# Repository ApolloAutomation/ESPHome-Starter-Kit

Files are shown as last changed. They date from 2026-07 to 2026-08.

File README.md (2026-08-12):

# Official ESPHome Starter Kit

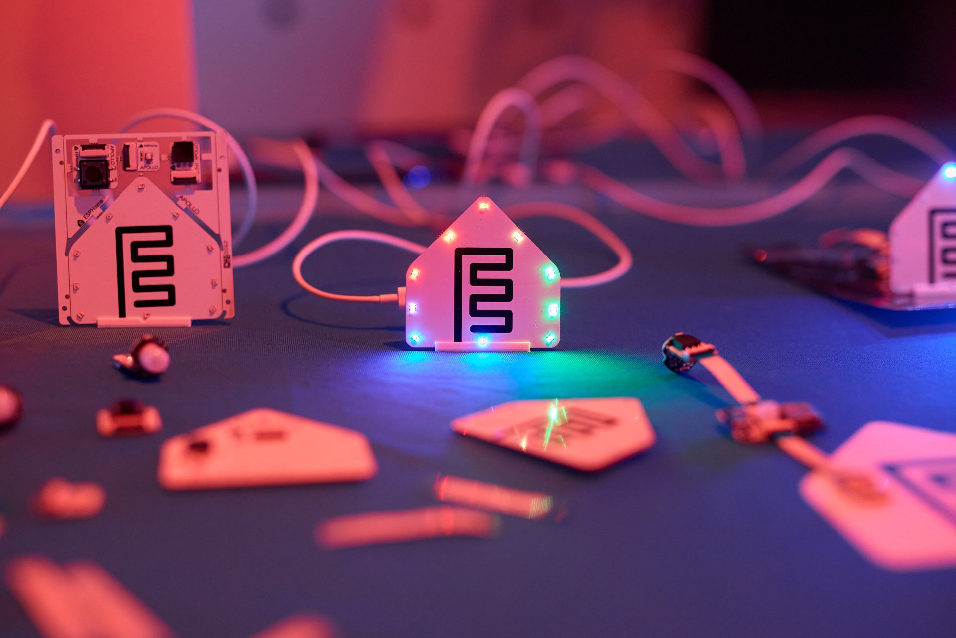
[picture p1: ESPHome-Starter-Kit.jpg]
ESPHome Starter Kit


The ESPHome Starter Kit is designed in collaboration with the **Open Home Foundation**. A portion of the profits from each sold goes directly to the OHF team to support their work on Home Assistant, ESPHome, Music Assistant, and other open-source smart home projects.

## Key Features

**ESP32-C6 Based:** Built on the ESP32-C6-mini module with Wi-Fi, Zigbee, and Thread radios for versatile smart home connectivity.

**Zigbee & Thread Support:** Dual antennas for Zigbee and Thread protocols. Supports Matter over Thread for future-proof smart home integration.

**USB-C Power:** USB-C port for easy power and programming.

**Expansion Ports:** Two 13-pin FPC cable ports allow you to connect and power virtually any sensor or accessory.

**Onboard Controls:** Boot and Reset buttons for easy flashing and debugging.

**Battery Powered:** Includes battery connector with MAX17048 fuel gauge for accurate voltage and percentage monitoring.

**Deep Sleep Support:** Configurable deep sleep duration for extended battery life. Wakes periodically to report sensor values and returns to sleep.

**Accessory Power Control:** GPIO-controlled power rail for connected accessories, automatically disabled during deep sleep to conserve battery.

## Specifications

| | |
|---|---|
| MCU | ESP32-C6-MINI-1 |
| Flash | 8 MB |
| Radios | Wi-Fi, Bluetooth, Zigbee, Thread |
| Framework | ESP-IDF (board `esp32-c6-devkitm-1`, variant `esp32c6`) |
| Power | USB-C, plus LiPo battery connector with MAX17048 fuel gauge |
| Expansion | Two 13-pin FPC ports with switchable accessory power rail |

## What's in the Kit

- **ESPHome C6 Board** - ESP32-C6 with dual FPC expansion ports
- **PIR Sensor** - Motion detection
- **Temperature/Humidity Sensor** - Environmental monitoring
- **Notification Puck** - LED and piezo buzzer PCB for visual and audio alerts
- **Button** - Physical input for triggering automations

## Pinout

| Function | GPIO |
|---|---|
| I2C SCL | GPIO0 |
| I2C SDA | GPIO1 |
| Motion module input (PIR) | GPIO3 |
| Accessory power (FPC rail control) | GPIO4 |
| Onboard RGB LED (WS2812) | GPIO5 |
| Button module input | GPIO6 |
| LED & Buzzer module LEDs (WS2812) | GPIO14 |
| LED & Buzzer module buzzer | GPIO18 |
| Boot button | GPIO9 |

### Breakout Module (optional add-on)

The [Breakout Module](https://wiki.apolloautomation.com/products/ESPHome-Starter-Kit/modules/apollo-breakout-module/) re-exposes the board's I2C bus and a shared GPIO across several connector types. It does not add new GPIOs.

| Connector | Signals |
|---|---|
| I2C ports (3.5mm jack, STEMMA QT 3.3V, STEMMA 5V, Grove, SEN6x) | SCL = GPIO0, SDA = GPIO1 |
| 1-Wire port | Data = GPIO6 |
| 3-pin STEMMA (5V) | GPIO6 (shared with 1-Wire), 5V, GND |
| 2x6 GPIO header | GPIO0 (SCL), GPIO1 (SDA), GPIO6, UART TX, UART RX, 3.3V, 5V, GND |

> **Note:** GPIO6 is shared between the 1-Wire port, the 3-pin STEMMA connector, and the GPIO header, so only one can be used at a time.

## ESPHome Integration

The starter kit is designed for use with ESPHome and Home Assistant. See the `Integrations/ESPHome/` folder for the YAML configuration.

### ESPHome Device Builder

The starter kit is an officially featured board in the [ESPHome Device Builder](https://github.com/esphome/device-builder). The easiest way to install firmware is straight from the Device Builder in your ESPHome dashboard — no default YAML to flash manually. You can see the board definition [here](https://github.com/esphome/device-builder/tree/main/esphome_device_builder/definitions/boards/apollo-esk-1).

## Hardware Files

3D models of the boards are in [`hardware/`](hardware/) for designing your own cases and mounts. Built something? See [CONTRIBUTING.md](CONTRIBUTING.md).

## Links

- **Product page:** [ESPHome Starter Kit on the Apollo shop](https://apolloautomation.com/products/esk-1-esphome-starter-kit)
- **Wiki (start here):** [ESPHome Starter Kit setup guide](https://wiki.apolloautomation.com/products/ESPHome-Starter-Kit/start-here/)
- **Forum:** [forum.apolloautomation.com](https://forum.apolloautomation.com/)
- **Discord** (support, feedback, discussion, future products): [dsc.gg/ApolloAutomation](http://dsc.gg/ApolloAutomation)
- **Open Home Foundation:** [openhomefoundation.org](https://www.openhomefoundation.org)

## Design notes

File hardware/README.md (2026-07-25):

# Hardware Files

3D models for the ESK-1 Starter Kit boards, provided so the community can design cases, mounts, and other accessories.

```
hardware/
├── cad/
│   └── pcb-placeholders/   # STEP models of each board — reference solids for case design
└── 3d-prints/
    └── Starter Kit Stand.stl
```

## `cad/pcb-placeholders/`

STEP models of the Starter Kit PCBs. These are **placeholders, not finished parts** — import them into your CAD tool as reference geometry to design enclosures and mounts that fit around the real boards.

| File | Board |
|---|---|
| `ESP32-C6 Mainboard.step` | ESK-1 main board |
| `PIR Module.step` | PIR motion sensor |
| `Temperature and Humidity Module.step` | Temp/humidity sensor |
| `LED and Buzzer Module.step` | Notification puck |
| `Button Module.step` | Button |
| `Breakout Module.step` | [Breakout Module](https://wiki.apolloautomation.com/products/ESPHome-Starter-Kit/modules/apollo-breakout-module/) (optional add-on, sold separately) |

## `3d-prints/`

Ready-to-print parts. Slice and print as-is.

| File | Part |
|---|---|
| `Starter Kit Stand.stl` | Display/desk stand for the kit |

## Contributing designs

Built a case or mount you'd like to share? See [CONTRIBUTING.md](../CONTRIBUTING.md).

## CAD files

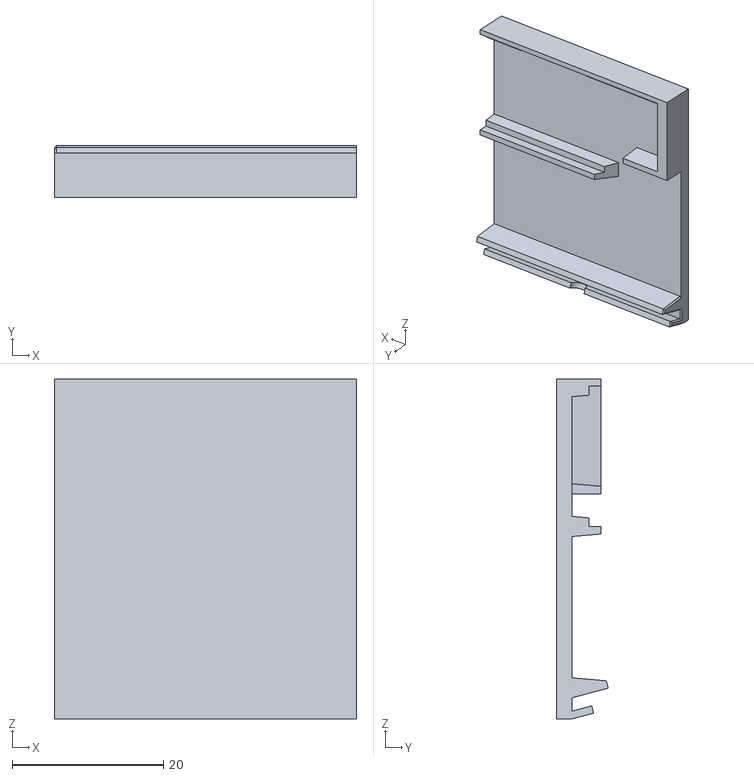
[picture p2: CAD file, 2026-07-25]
hardware/3d-prints/Starter Kit Stand.stl
40.0 x 6.83 x 45.0

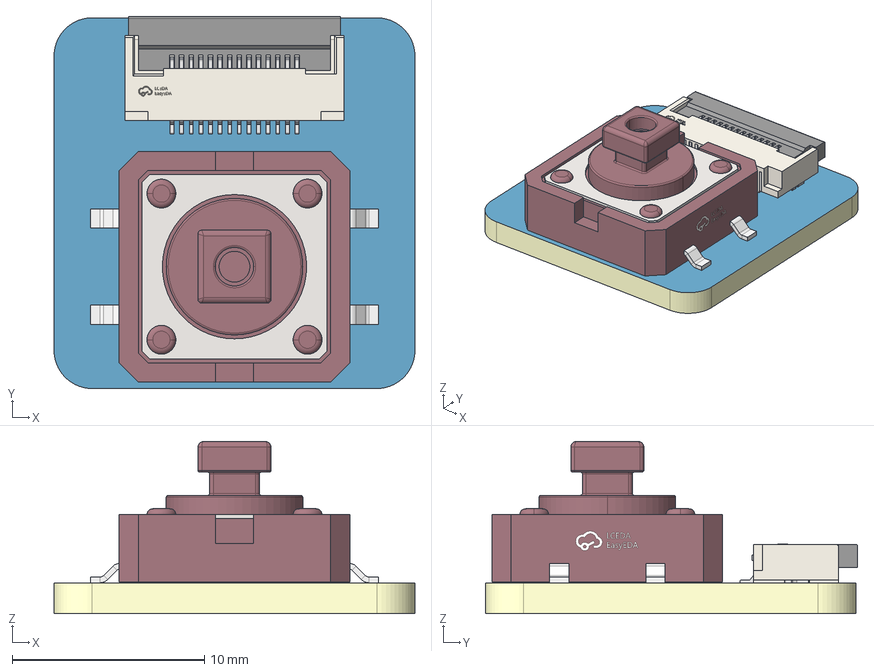
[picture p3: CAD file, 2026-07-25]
hardware/cad/pcb-placeholders/Button Module.step
18.8 x 19.3 x 8.95 mm
Board~eu64
TopCopper~eu64
BottomCopper~eu64
TopFpcStiffener~eu64
BottomFpcStiffener~eu64
KEY-SMD_4P-L12.0-W12.0-P5.00-LS15.0~KEY-SMD_ 4P-L12.0-W12.0-H7.3-LS15.0-P5.0~eu64
FPC-SMD_AFC01-S14FCA-00~FPC-SMD_AFC01-S14FCA-00~eu64

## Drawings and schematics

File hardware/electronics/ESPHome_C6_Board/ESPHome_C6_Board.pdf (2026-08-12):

# USB Connector Step Down 3.3V Handling

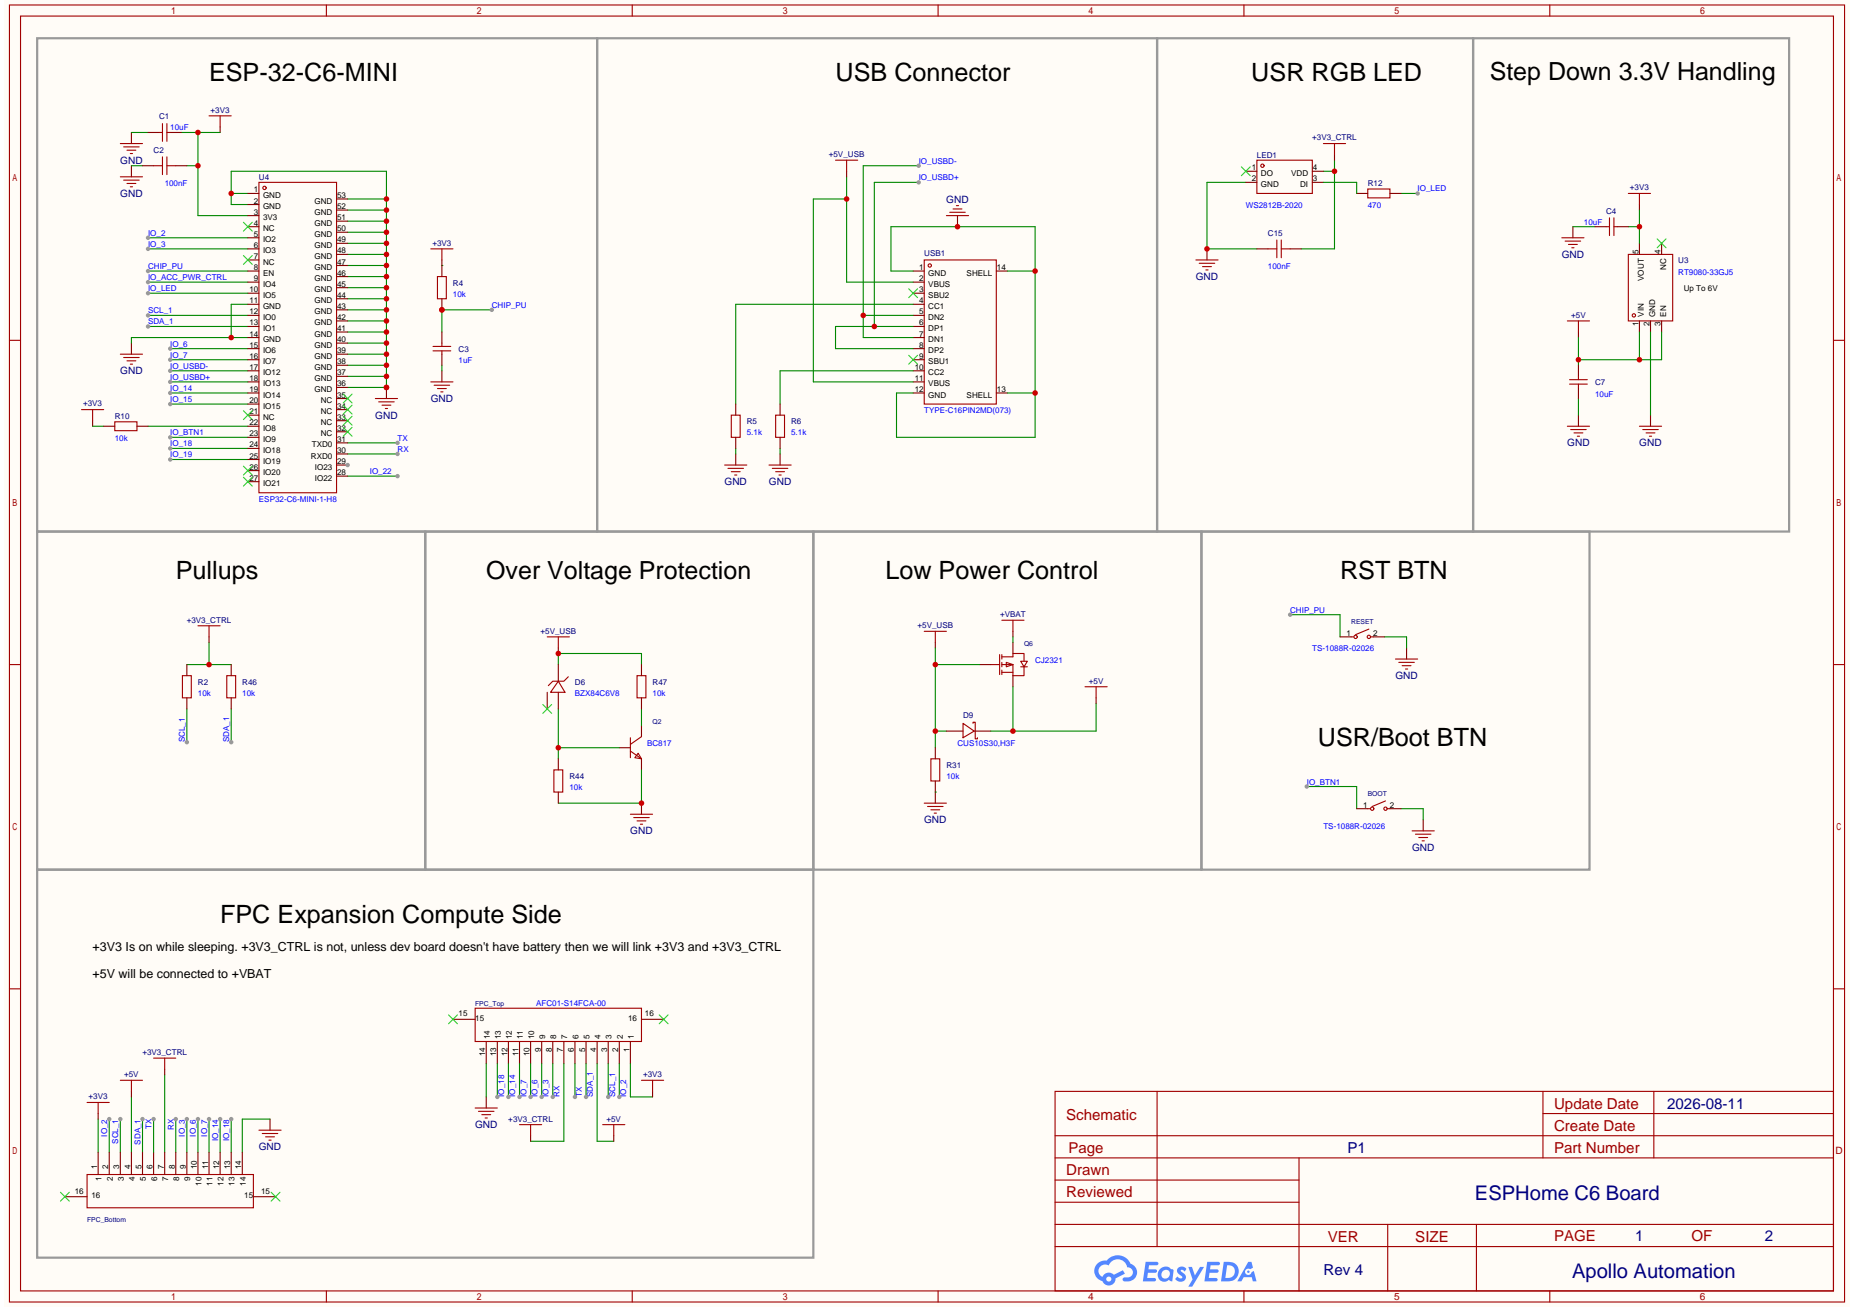
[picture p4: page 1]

FPC Expansion Compute Side

+3V3 Is on while sleeping. +3V3_CTRL is not, unless dev board doesn't have battery then we will link +3V3 and +3V3_CTRL

# Battery Measurement

# Battery Protection

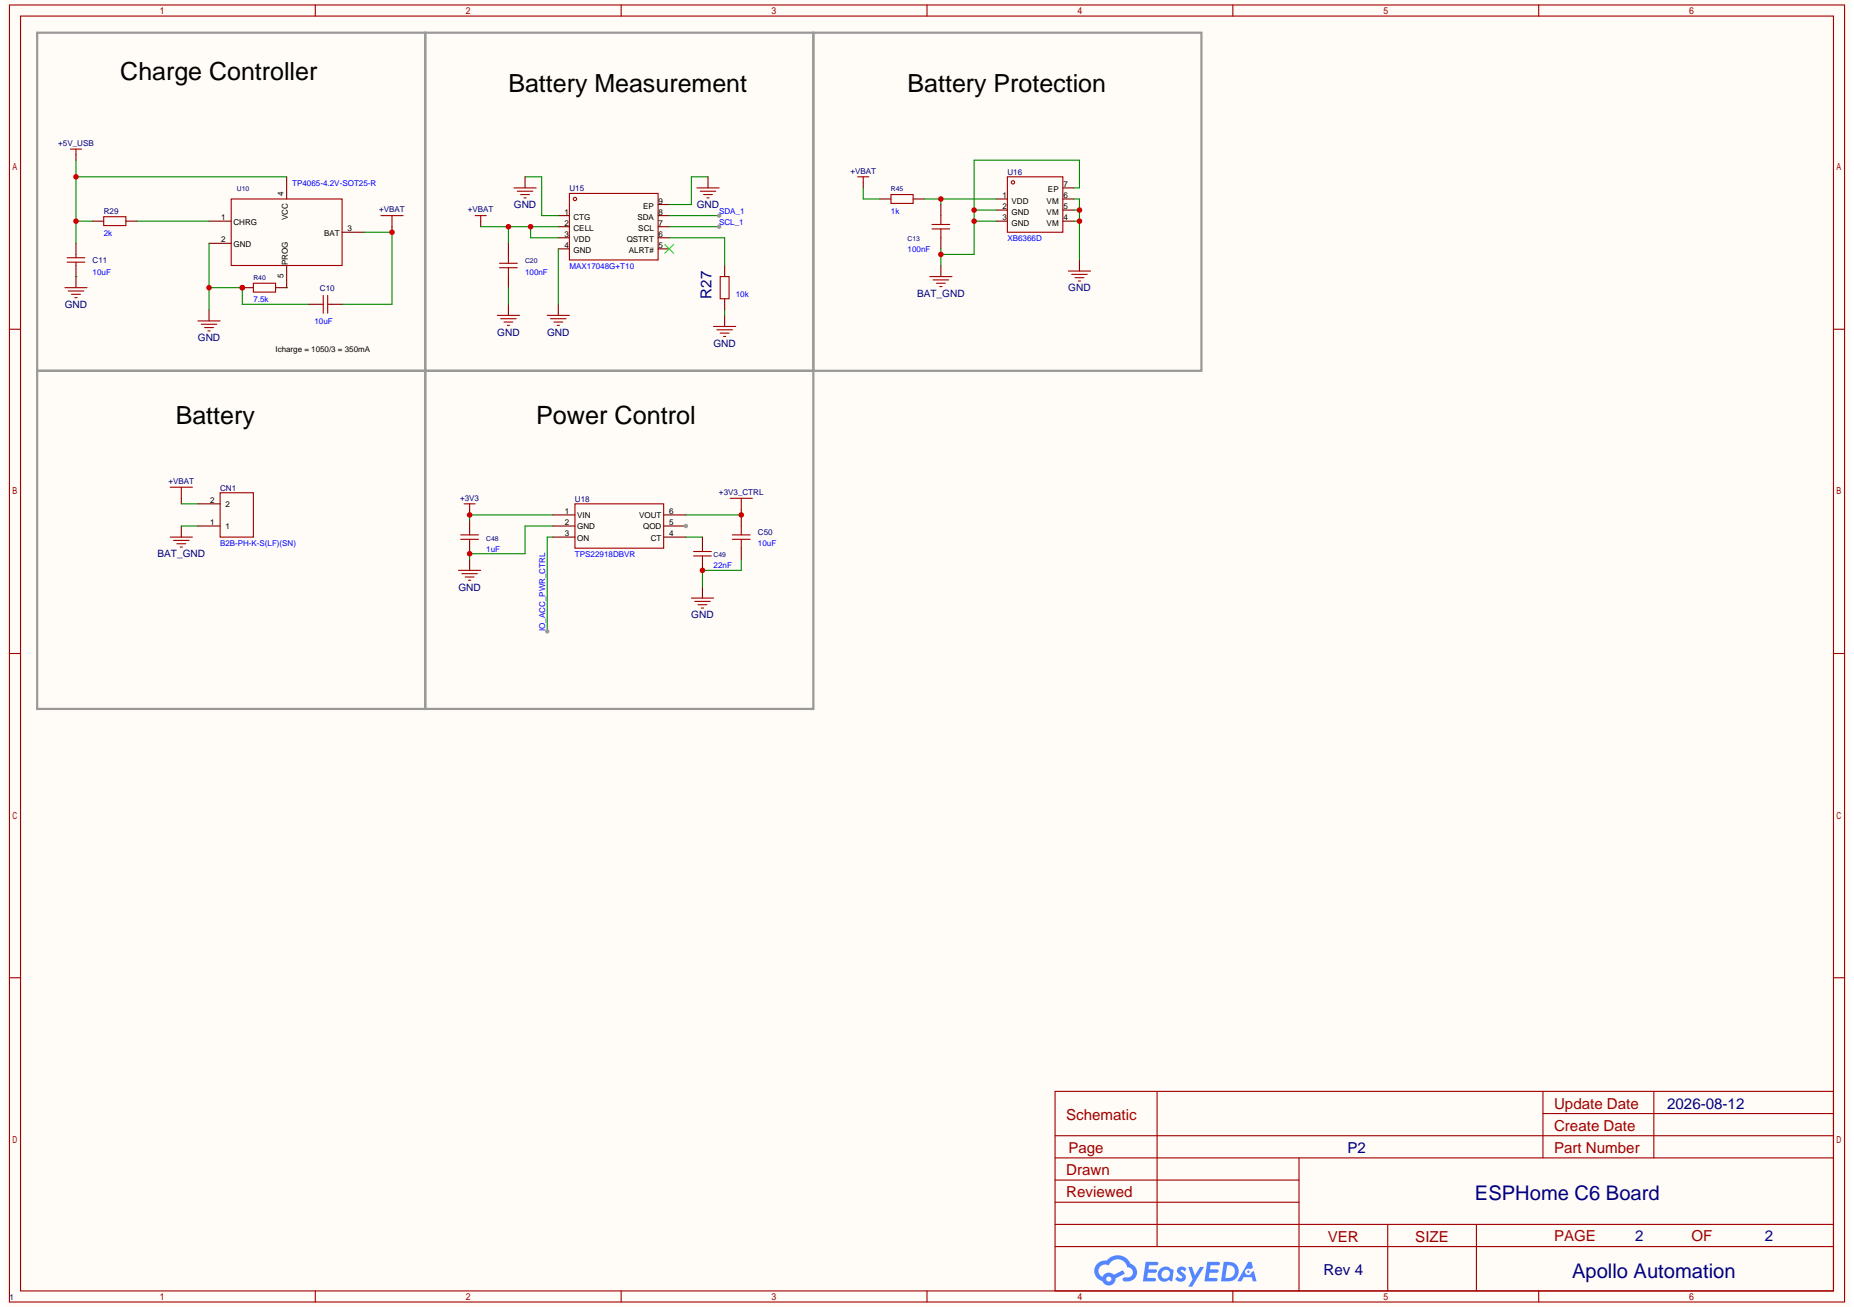
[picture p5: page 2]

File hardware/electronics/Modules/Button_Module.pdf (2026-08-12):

FPC Expansion | Button

# Bridge To Select Button Pin

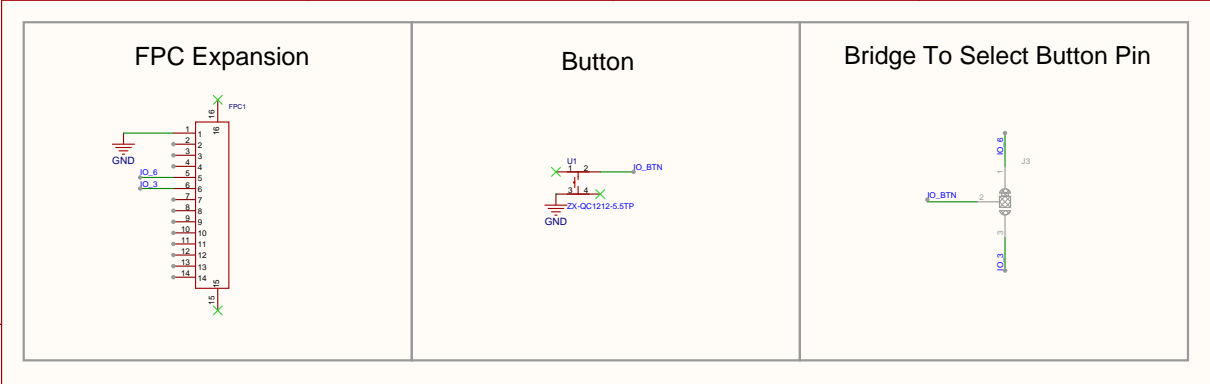
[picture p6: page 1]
Reviewed; Drawn; VER; Create Date Part Number; PAGE; Schematic; Update Date; SIZE; Page; StarterKit_Button; Rev 1; Apollo Automation; IO_BTN; GND; FPC1

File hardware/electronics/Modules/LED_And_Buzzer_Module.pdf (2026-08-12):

# FPC Expansion

## +3V3 Is on while sleeping. +3V3_CTRL is not ¹⁶ ¹⁶ ¹⁵ ¹⁵

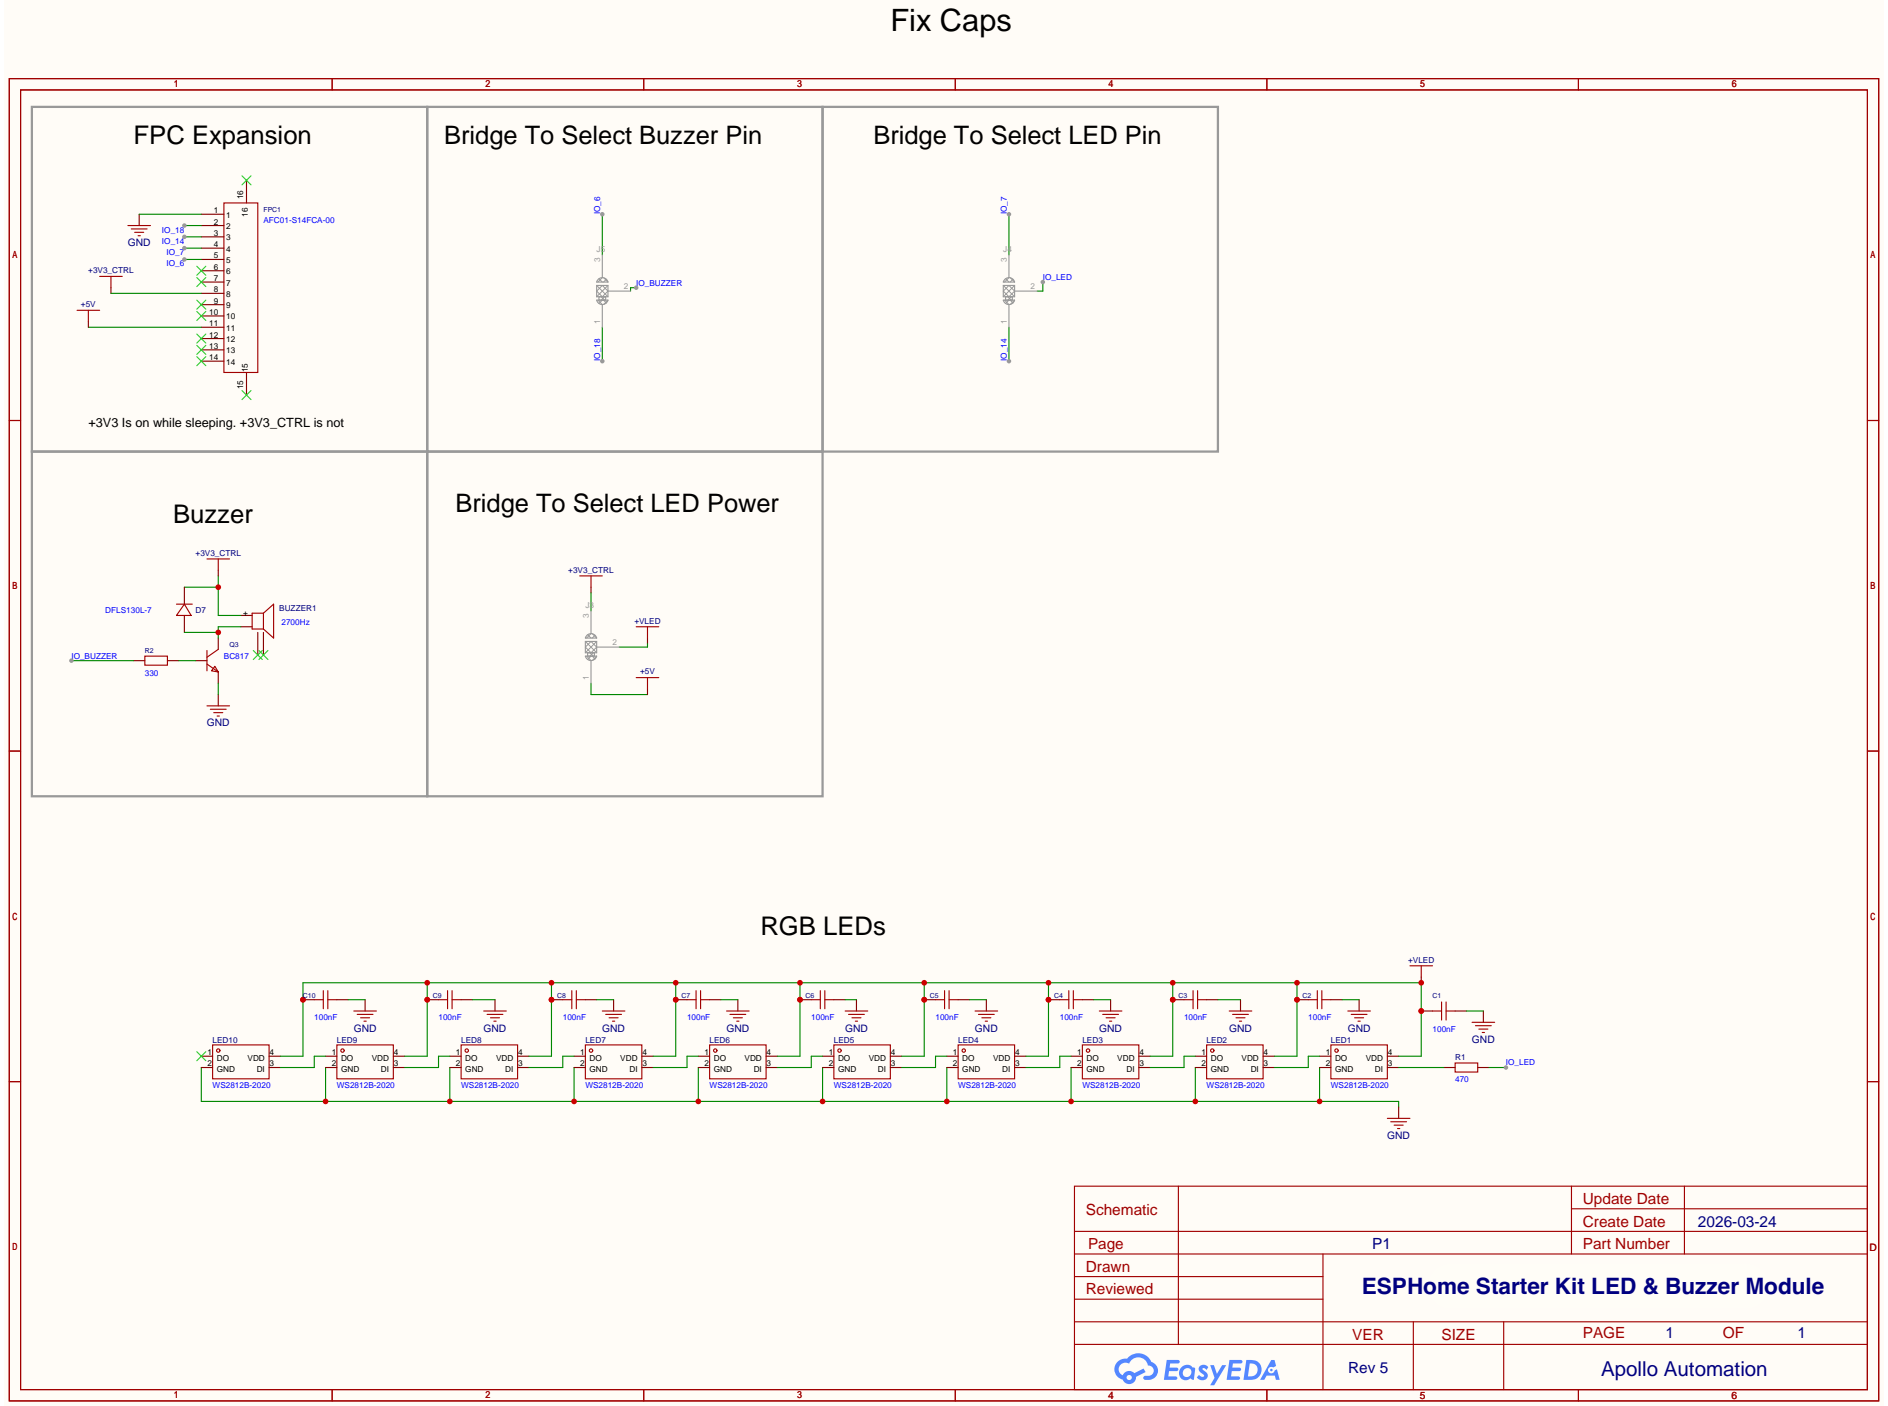
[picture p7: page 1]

Bridge To Select LED Power

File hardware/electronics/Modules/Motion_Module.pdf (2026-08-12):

FPC Expansion | PIR Connector | Bridge To Select PIR Pin

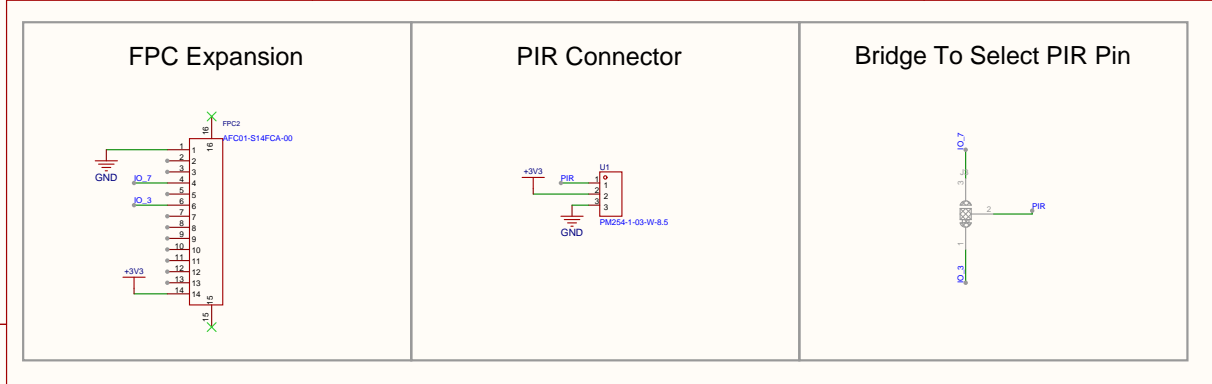
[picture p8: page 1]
Reviewed; Drawn; VER; Create Date Part Number; PAGE; Schematic; Update Date; SIZE; Page; StarterKit_PIR; Rev 3; Apollo Automation; FPC2 AFC01-S14FCA-00; PIR; GND; +3V3 GND; PIR IO_3

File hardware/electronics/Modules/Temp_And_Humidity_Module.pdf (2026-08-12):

# AHT20

# FPC Expansion

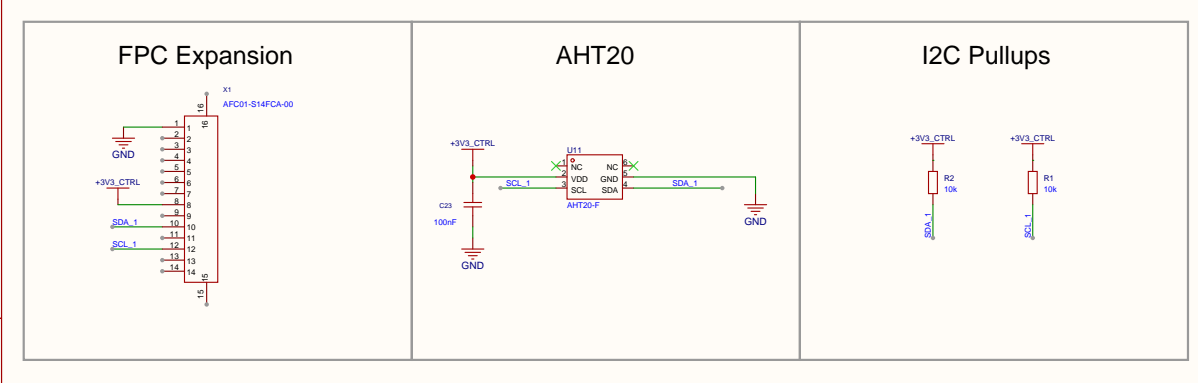
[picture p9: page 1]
Reviewed; Drawn; VER; Create Date Part Number; PAGE; Schematic; Update Date; SIZE; Page; StarterKit_AHT20; Rev 2; Apollo Automation; NC 1 VDD 2; SCL 3; SDA 4; GND 5; AHT20-F; GND; SCL_1; SDA_1; +3V3_CTRL; +3V3_CTRL SDA_1; X1 AFC01-S14FCA-00; I2C Pullups

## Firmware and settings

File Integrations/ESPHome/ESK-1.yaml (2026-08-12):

substitutions:
  name: apollo-esk-1
  version: "25.1.29.1"
  device_description: ${name} made by Apollo Automation - version ${version}.

esphome:
  name: "${name}"
  friendly_name: Apollo ESK-1
  comment: Apollo ESK-1 Starter Kit
  name_add_mac_suffix: true
  platformio_options:
    board_build.flash_mode: dio

  project:
    name: "ApolloAutomation.ESK-1"
    version: "${version}"

  min_version: 2023.11.1

  on_shutdown:
    - light.turn_off: rgb_light
    - switch.turn_off: accessory_power

  on_boot:
    - priority: 500
      then:
        - lambda: |-
            id(deep_sleep_1).set_sleep_duration(id(deep_sleep_sleep_duration).state * 60 * 60 * 1000);
        - if:
            condition:
              or:
                - binary_sensor.is_on: ota_mode
                - switch.is_on: prevent_sleep
            then:
              - lambda: |-
                  ESP_LOGW("Apollo", "Preventing Deep Sleep Due To OTA On Boot");
                  id(deep_sleep_1).prevent_deep_sleep();

esp32:
  variant: esp32c6
  flash_size: 8MB
  framework:
    type: esp-idf

#external_components:
#  - source: github://ApolloAutomation/esphome-battery-component
#    components: [max17048]

api:
  id: api_server
  reboot_timeout: 0s
  on_client_connected:
    then:
      - delay: 5s
      - if:
          condition:
            or:
              - binary_sensor.is_on: ota_mode
              - switch.is_on: prevent_sleep
          then:
            - lambda: |-
                ESP_LOGW("Apollo", "Preventing Deep Sleep Due To OTA Or Switch");
                id(deep_sleep_1).prevent_deep_sleep();
          else:
            - lambda: |-
                id(reportAllValues).execute();
            - delay: 2s
            - deep_sleep.enter:
                id: deep_sleep_1

#########
######### Buzzer Module Start
#########
  services:
    - service: play_buzzer
      variables:
        song_str: string
      then:
        - rtttl.play:
            rtttl: !lambda 'return song_str;'

output:
  - platform: ledc
    pin: GPIO18
    id: buzzer
rtttl:
  id: rtttl_buzzer
  output: buzzer
#########
######### Buzzer Module End
#########

ota:
  - platform: esphome
    id: ota_esphome

wifi:
  ap:
    ssid: "Apollo ESK-1 Hotspot"

logger:

captive_portal:

i2c:
  - id: i2c_bus
    sda: GPIO1
    scl: GPIO0

#########
######### DS18b20 Probe Start
#########
one_wire:
  - platform: gpio
    pin: GPIO6
#########
######### DS18b20 Probe End
#########



deep_sleep:
  id: deep_sleep_1
  sleep_duration: 24h
  run_duration: 90s

number:
  - platform: template
    name: "Sleep Duration"
    id: deep_sleep_sleep_duration
    min_value: 0
    max_value: 800
    step: 1
    mode: box
    update_interval: never
    optimistic: true
    restore_value: true
    initial_value: 24
    icon: "mdi:arrow-collapse-right"
    entity_category: CONFIG
    unit_of_measurement: "h"
    on_value:
      then:
        - lambda: |-
            id(deep_sleep_1).set_sleep_duration(x * 60 * 60 * 1000);

binary_sensor:
  - platform: status
    name: Online
    id: ink_ha_connected

  - platform: homeassistant
    name: "OTA Mode"
    id: ota_mode
    entity_id: input_boolean.apollo_ota_mode
    on_press:
      then:
        - lambda: |-
            id(deep_sleep_1).prevent_deep_sleep();
    on_release:
      then:
        - if:
            condition:
              switch.is_off: prevent_sleep
            then:
              - lambda: |-
                  id(deep_sleep_1).allow_deep_sleep();
#########
######### PIR Module Start
#########

  - platform: gpio
    name: "PIR"
    pin:
      number: GPIO3
      mode:
        input: true
        pulldown: false
    id: io_pir
    device_class: motion

#########
######### PIR Module End
#########

#########
######### Button Module Start
#########

##  -   platform: gpio
##      id: button_1
##      name: "Button 1"
##      pin:
##        number: GPIO6
##        mode:
##          input: true
##          pullup: true
##        inverted: true
##      on_press:
##        then:
##          - logger.log: "Button 1 pressed"

#########
######### Button Module End
#########

sensor:
  - platform: internal_temperature
    name: "ESP Temperature"
    id: sys_esp_temperature
    disabled_by_default: true

  - platform: uptime
    name: Uptime
    id: sys_uptime
    update_interval: 60s

  - platform: wifi_signal
    name: RSSI
    id: wifi_signal_db
    update_interval: 60s
    entity_category: "diagnostic"

  - platform: sht4x
    id: sht41
    temperature:
      name: "SHT41 Temperature"
      id: sht41_temperature
    humidity:
      name: "SHT41 Relative Humidity"
      id: sht41_humidity
    update_interval: 60s

#########
######### DS18b20 Probe Start
#########
  - platform: dallas_temp
    name: "Temperature Probe"
    update_interval: 60s
    id: temp_probe
    index: 0
#########
######### DS18b20 Probe End
#########
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

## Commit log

2026-01-29 Battery, deep sleep, and LED working.
2026-07-13 Add hardware models, clean up repo structure
    - Add hardware/ with STEP placeholder models of each board (cad/pcb-placeholders)
    and the printable Starter Kit Stand (3d-prints), plus a hardware README
    - Remove leftover AIR-1 ESP Web Tools installer (index.html); the Starter Kit
    is a DIY board with no default flashable firmware to host
    - Rename License.md to LICENSE.md so GitHub detects the CC BY-NC-SA 4.0 license
    - Add CONTRIBUTING.md inviting community case designs
    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
    [Button Module.step, Starter Kit Stand.stl]
2026-07-13 Use official product name, store photo, links; drop unimplemented features
    - Rename README title to "ESPHome Starter Kit (ESK-1)" to match the
    official product name
    - Replace bare-PCB render with the store hero photo (ESPHome-Starter-Kit.jpg)
    - Add "buy" and "start here" wiki links to the README
    - Remove RGB status LED battery-color logic and the Prevent Sleep Toggle
    from Key Features (neither is implemented)
2026-07-13 Fix links list and correct the pinout table
    - Rework the Links section into a bullet list (one per line) and add the
    product page, the start-here wiki page, and the community forum
    - Correct the pinout: I2C is GPIO0/1 (not 20/21, which are commented out),
    and add the motion, button, LED & buzzer module, and boot-button pins per
    the device-builder manifest and ESK-1.yaml
2026-07-13 Add Breakout Module pinout to README
    Document the optional Breakout Module's connectors (I2C ports, 1-Wire,
    3-pin STEMMA, and the 2x6 GPIO header) and note that GPIO6 is shared, per
    the wiki. These re-expose existing board GPIOs rather than adding new ones.
2026-07-13 Add Specifications section and ESPHome Device Builder install note
    - Add a Specifications table (MCU, flash, radios, framework, power,
    expansion) sourced from the device-builder manifest
    - Note that the ESK-1 is a featured board in the ESPHome Device Builder and
    link the board definition, since there is no default YAML to flash manually
2026-08-12 YAML Cleanup And Schematics
    [Drill_NPTH_Through.DRL, Drill_PTH_Through.DRL, Drill_PTH_Through_Via.DRL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]
